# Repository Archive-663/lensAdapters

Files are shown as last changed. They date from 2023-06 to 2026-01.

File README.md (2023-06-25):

# Lot no. 002 | Lens Adapters

A collection of lens adapters for a wide variety of cameras.

I'm working on a fully 3d printed adapter for lenses that require a lens locking pin so that the adapters can reach a wider audience without having to buy specialised parts like prewound springs or 2mm rods.

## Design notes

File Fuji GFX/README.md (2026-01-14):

## FujiFilm GFX Lens Adapters

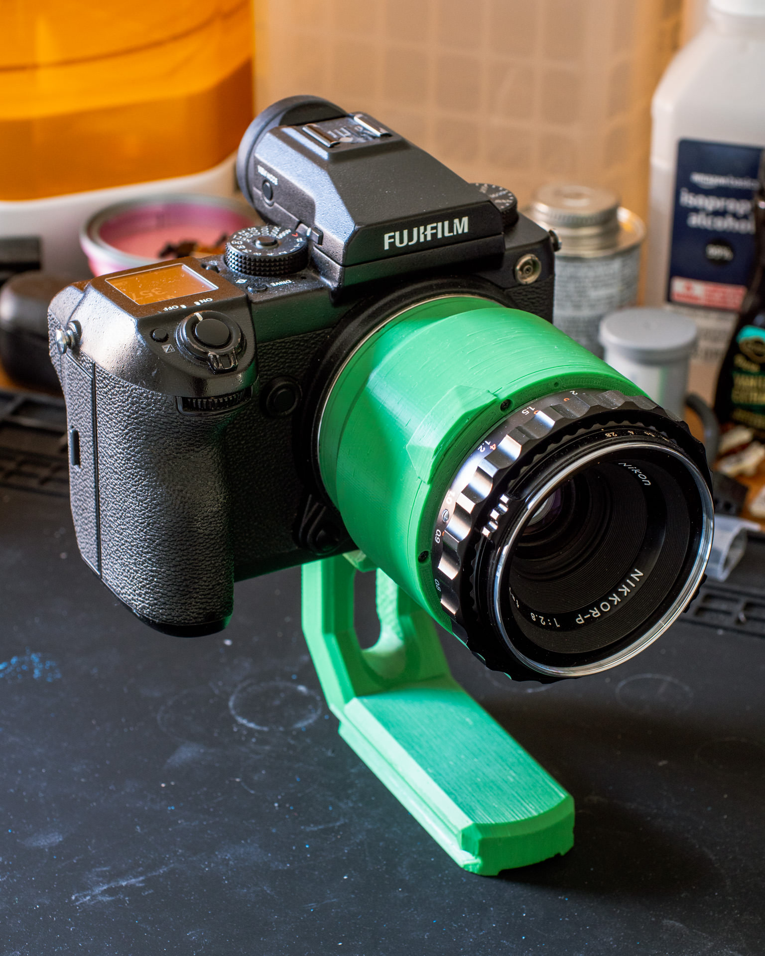
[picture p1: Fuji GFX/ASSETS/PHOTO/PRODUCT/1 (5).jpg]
GFXlensAdapter


### In this repository:
- [GFX Dumb Lens Adapters](https://github.com/Archive-663/lensAdapters/tree/main/Fuji%20GFX/DUMB)

### Story Time:
The GFX has always been my grail camera. While yes, this is old and some what cumbersom, the images coming from the sensor are amazing. The adapters for the GFX are expensive, and unsurprisingly, I'm a cheap ass. So I've spent some time making a few dumb adapters for the GFX. I'm in the process of designing a shift adapter for certain mounts as well, but they will come later.

### Help support Archive 663 with a dontation or monthly sub



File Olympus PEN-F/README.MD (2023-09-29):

# Olympus PEN-F Dumb, Shift, and Speedbooster Adapters

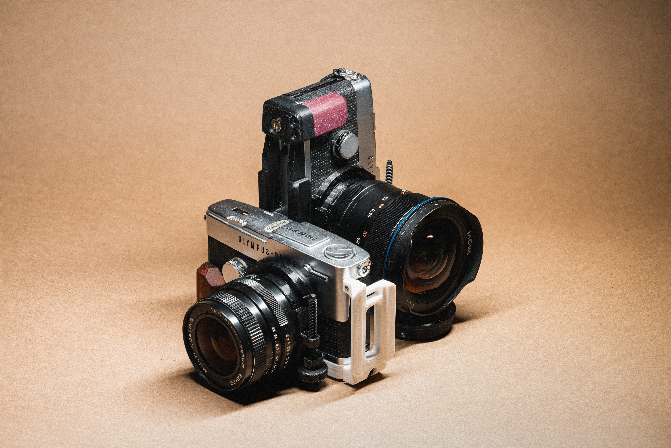
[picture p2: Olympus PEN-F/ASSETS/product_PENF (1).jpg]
productPhoto001


### In this repository:
- [Pen-F Dumb Lens Adapters](https://github.com/Archive-663/lensAdapters/tree/main/Olympus%20PEN-F/DUMB)
- [Pen-F Shift Lens Adapters](https://github.com/Archive-663/lensAdapters/tree/main/Olympus%20PEN-F/SHIFT)
- [Pen-F Speedbooster Lens Adapters](https://github.com/Archive-663/lensAdapters/tree/main/Olympus%20PEN-F/SPEEDBOOSTER)

### Story Time:
I picked up an Olympus PEN-F a while ago to see if there was any chance I could adapt some modern APS-C mirrorless or DLSR lenses to better it's lens selection. The unfortunate answer is that it's mostly "no." While the flange focal distance is pretty short, the mirror actually protrudes too much into the actual lens mount so more often than not the mirror would slap the rear lens element of most adapted mirrorless and even Leica M mount lenses. There is hope for APS-C DSLR lenses. I'm working on adapting a zoom lens and trying to figure out how to make a much more compact circular fish eye lense out of a few Meike lenses.

So while mirrorless lenses were out of the question, there was still a significant gap between me using DSLR lenses on my PEN-F. I could only find a third-party EF to PEN-F adapter and the official PEN-F adapters were few and far between online. So, I figured let's fix that issue while having some fun. I started with the M42 mount because the mount is pretty easy to build on since there are no moving parts that engage from the camera mount to the lens flange. But really, the only way to open up more lenses was to develop an easy to print and assemble Nikon F and Canon EF adapter.

Since, both, Canon and Nikon have a pin lock system, I needed to design a reliable pin locking system that was easy to print with few bought parts. I came up with a simple wedge lever locking system to positively engage the locking pins into the cavity on the lens flanges. It works reliably, prints well, and doesn't require any premade springs or parts. I wanted to do it this way to increase the accessiblilty of the adapters. With fewer parts that need to be bought it's easier for anyone in the world to print, assemble, and use; only having to purchase standardized M1.6 x 6mm machine screws.

Funnily enough, the designing of the shift lenses required me to design an L-Bracket system for the Pen-F cameras. Which can be found here: [Lot no. 007 | Olympus Pen-F accessories](https://github.com/Archive-663/olympusPENF)

### Help support Archive 663 with a dontation or monthly sub



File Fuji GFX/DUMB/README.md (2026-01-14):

## GFX Dumb Lens Adapters

A collection of basic dumb adapters for using non-Fuji GFX lenses on Fuji GFX cameras.

### Features:
- Available for Bronica S2.
- More mounts coming soon.

### To Print:
- Download the files in the mountDumbBase folder for the GFX Mount
- Download the files for the camera mount you want to adapt. They all use the same GFX mount so keeping them separate makes it easier to update when I need to. 

### Help support Archive 663 with a dontation or monthly sub



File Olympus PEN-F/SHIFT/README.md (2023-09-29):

## PEN-F Shift Lens Adapters

olympusPENFShiftAdapters

A collection of basic shift adapters for using SLR/DSLR lenses on Olympus Pen-F cameras.

### Features:
- +/- 7mm of shift.
- 90 degree rotation for both portrait and landscape shift.
- Available for M42, & Nikon F.
- Interchangeable base PEN-F bottom shift assembly. Print once and slide on and off either of the top shift assemblies.
- More mounts coming soon.

### Help support Archive 663 with a dontation or monthly sub



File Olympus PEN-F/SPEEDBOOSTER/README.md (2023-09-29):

## PEN-F Speedbooster Lens Adapters

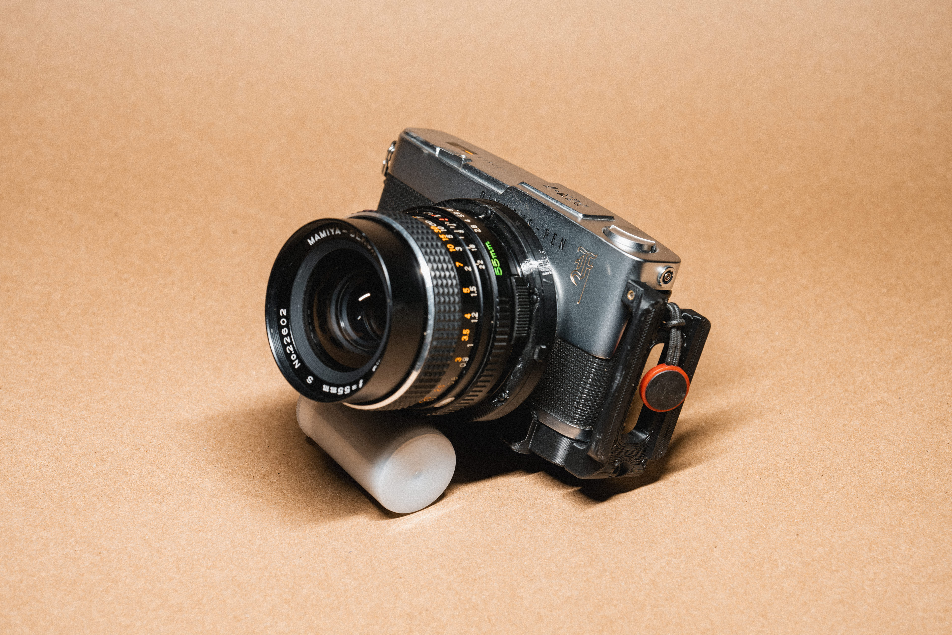
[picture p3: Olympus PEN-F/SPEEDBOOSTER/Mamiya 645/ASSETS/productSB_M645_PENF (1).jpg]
olympusPENFSpeedboosterAdapters


A collection of experimental shift adapters for using Medium Format lenses on Olympus Pen-F cameras.

### Features:
- 0.71x focal reduction
- More mounts coming soon.

### Help support Archive 663 with a dontation or monthly sub



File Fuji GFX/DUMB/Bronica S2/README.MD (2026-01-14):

## Bronica S2 to Fuji GFX Dumb Adapter

productPhoto001

### Features:
- All-in-one Coil Spring Aperture Lever
- Print in place Lens Lock/Release

### What you'll need:
- 12x M1.6 x 5mm pan head or self-tapping screws
- 1x M1.6 tap (If using a machine screw)

### What would be helpful:
- M1.4 drill bit
- M1.8/M2 drill bit

### Printing help:
Filament recommendation:
- ABS
- PETG

Generally, all my designs have chamfers on the print face of the STL. You can reference the supplied 'printOrientation' .3mf files for suggested print orientation.

### Assembly help:
Drill holes to their correct tap size before tapping.
- M1.6 requires M1.4 bore followed by an M1.6 tap.
- M1.8 or M2 bore on flanges.

To assemble correctly, use indexing dots to orient the parts. For the Aperture Lever Spring, the indexing dot should point up if looking straight through the dumb body.

Please view the _assembly.stp file for help in parts orientation. If you do not have a CAD program, <a href="https://www.freecad.org/downloads.php" target="_blank">download FreeCAD</a> to view the assembly file and better understand how it should assemble. If using FreeCAD, the naming conventions should carry over and you will be able to see which lens element you need from the various smartphone lenses. (Verified in FreeCAD 0.18) If using something like Solid Edge open the file as an assembly to retain the names of the parts.

### Help support Archive 663 with a dontation or monthly sub



### Samples:
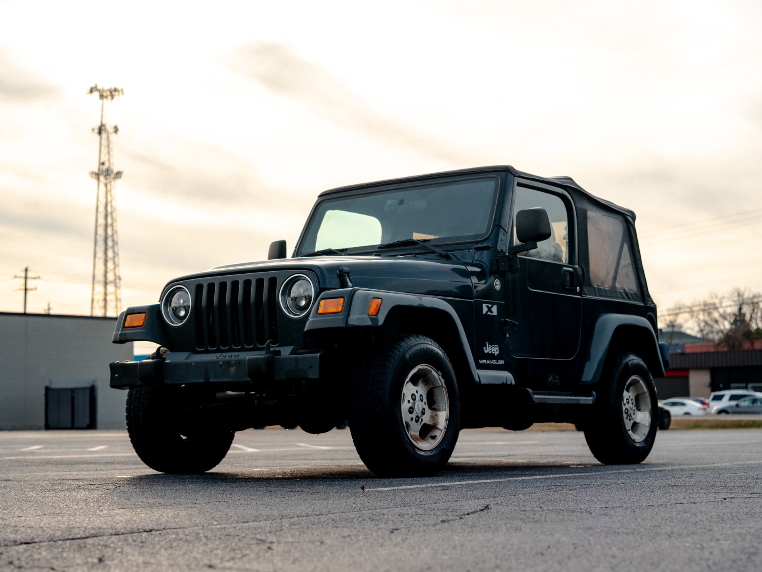
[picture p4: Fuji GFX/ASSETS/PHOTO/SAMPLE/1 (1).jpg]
samplePhoto001

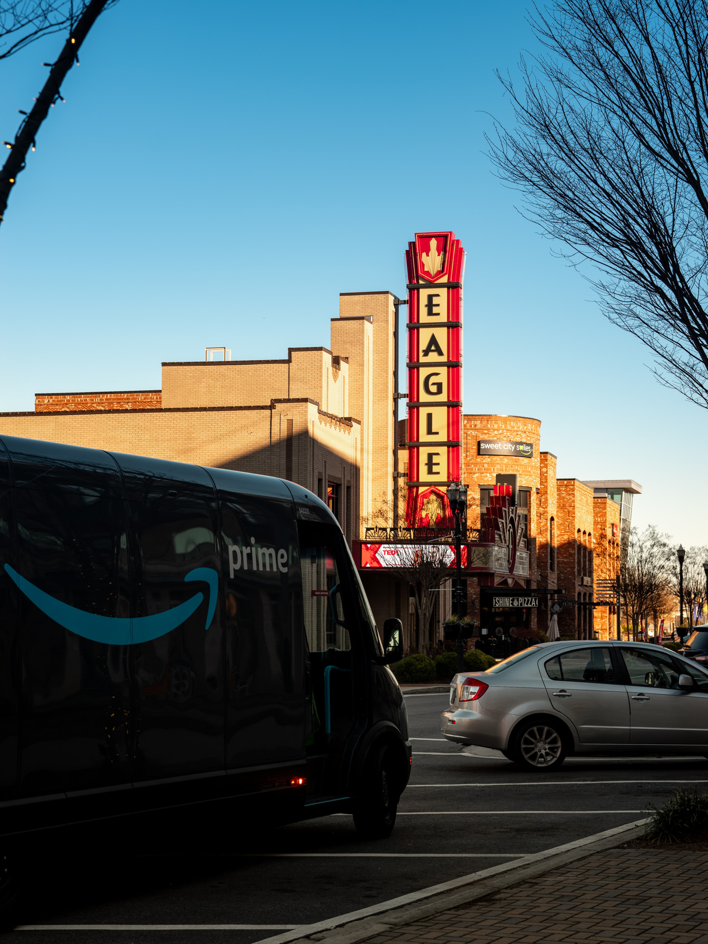
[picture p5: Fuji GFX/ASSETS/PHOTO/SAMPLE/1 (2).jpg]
samplePhoto002

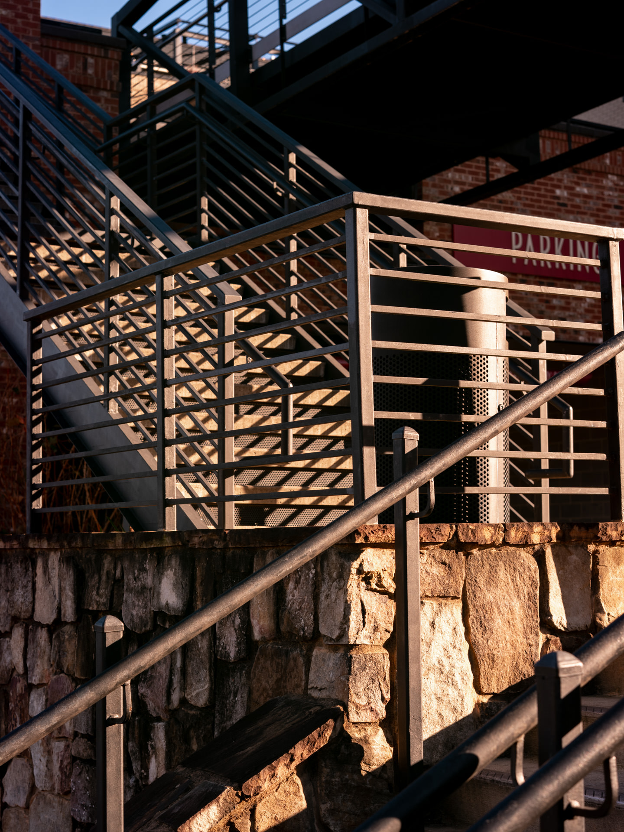
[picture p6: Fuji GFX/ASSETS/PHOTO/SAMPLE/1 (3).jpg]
samplePhoto003

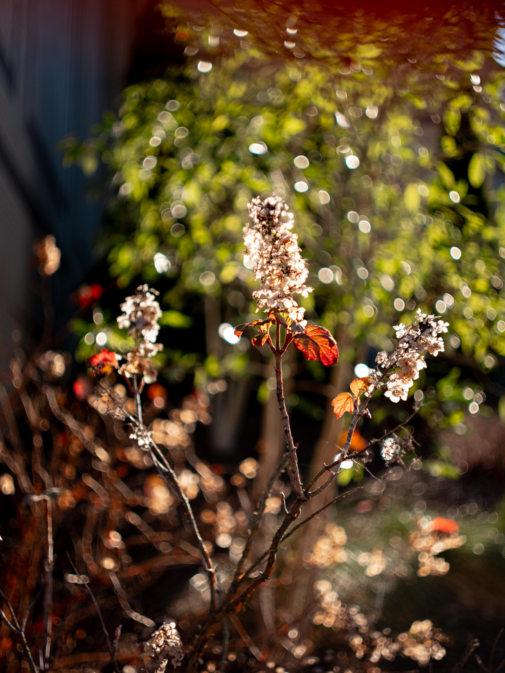
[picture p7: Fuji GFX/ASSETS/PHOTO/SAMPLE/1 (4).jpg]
samplePhoto004


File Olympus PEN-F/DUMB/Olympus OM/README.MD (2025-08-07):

## Olympus OM to PEN-F Dumb Adapter

### Features:
- Adapts OM lenses to PEN-F

### What you'll need:
- 7x M1.6 x 5mm pan head or self-tapping screws
- 1x M1.6 tap (if using standard machine screws and not self-tapping)

### What would be helpful:
- M1.4 drill bit
- M1.8/M2 drill bit

### Printing help:
Filament recommendation:
- ABS
- PETG

Generally, all my designs have chamfers on the print face of the STL. You can reference the supplied 'printOrientation' .3mf files for suggested print orientation.

### Assembly help:
Download the PEN-F mount and locking pin under the mountDumbBase_PENF folder in the DUMB adapters folder on github

Drill holes to their correct tap size before tapping.
- M1.6 requires M1.4 bore followed by an M1.6 tap.
- M1.8 or M2 bore on Rotator part.

To assemble correctly, use indexing dots to orient the parts.

Please view the _assembly.stp file for help in parts orientation. If you do not have a CAD program, <a href="https://www.freecad.org/downloads.php" target="_blank">download FreeCAD</a> to view the assembly file and better understand how it should assemble. If using FreeCAD, the naming conventions should carry over and you will be able to see which lens element you need from the various smartphone lenses. (Verified in FreeCAD 0.18) If using something like Solid Edge open the file as an assembly to retain the names of the parts.

### Help support Archive 663 with a dontation or monthly sub



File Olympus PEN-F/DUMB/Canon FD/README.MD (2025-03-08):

## Canon FD to PEN-F Dumb Adapter

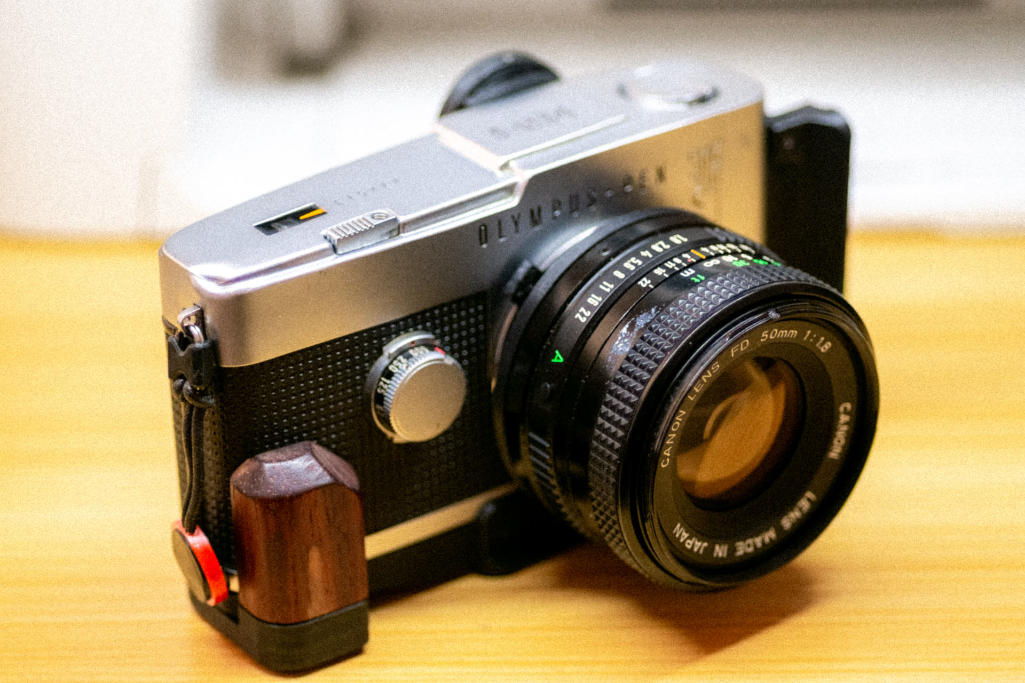
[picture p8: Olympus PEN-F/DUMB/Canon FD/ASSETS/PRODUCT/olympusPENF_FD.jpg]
productPhoto001


### Features:
- Simple aperture pin lock.

productPhoto002

### What you'll need:
- 3x M1.6 x 5mm pan head or self-tapping screws
- 1x M1.6 tap

### What would be helpful:
- M1.4 drill bit
- M1.8/M2 drill bit

### Printing help:
Filament recommendation:
- ABS
- PETG

Generally, all my designs have chamfers on the print face of the STL. You can reference the supplied 'printOrientation' .3mf files for suggested print orientation.

### Assembly help:
Drill holes to their correct tap size before tapping.
- M1.6 requires M1.4 bore followed by an M1.6 tap.
- M1.8 or M2 bore on Rotator part.

To assemble correctly, use indexing dots to orient the parts.

Please view the _assembly.stp file for help in parts orientation. If you do not have a CAD program, <a href="https://www.freecad.org/downloads.php" target="_blank">download FreeCAD</a> to view the assembly file and better understand how it should assemble. If using FreeCAD, the naming conventions should carry over and you will be able to see which lens element you need from the various smartphone lenses. (Verified in FreeCAD 0.18) If using something like Solid Edge open the file as an assembly to retain the names of the parts.

### Help support Archive 663 with a dontation or monthly sub



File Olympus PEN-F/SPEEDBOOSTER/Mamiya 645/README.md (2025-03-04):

## M645 to PEN-F Speedbooster Adapter

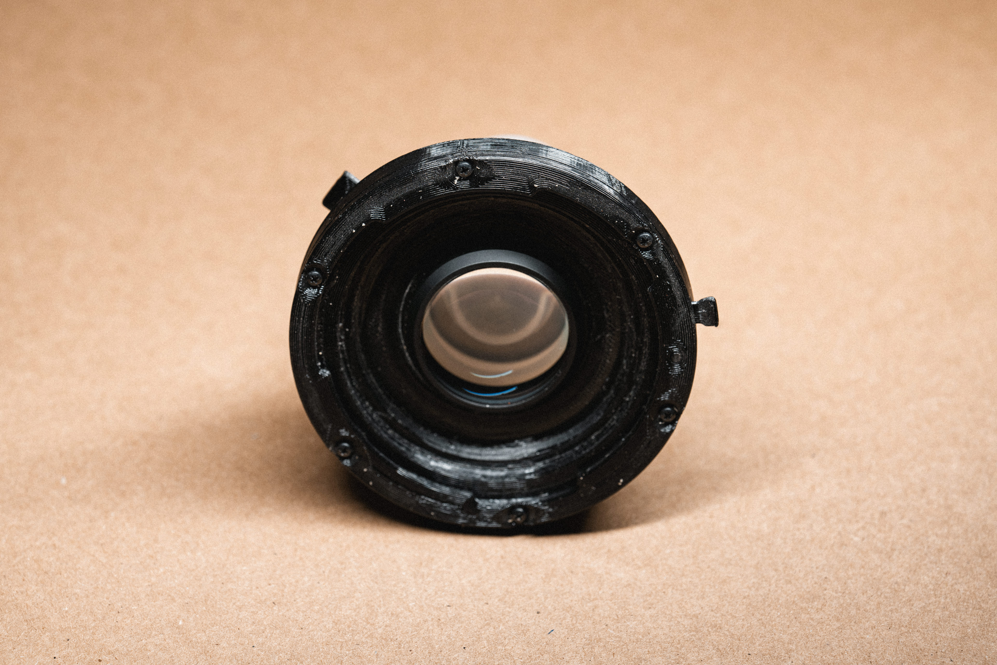
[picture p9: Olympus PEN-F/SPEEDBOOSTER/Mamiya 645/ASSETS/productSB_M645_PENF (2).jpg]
olympusPENFSpeedboosterAdapterforM645Lenses


### Features:
- 0.71x focal reduction

### What you'll need:
- Viltrox or similar speedbooster/focal reducer element
- 9x M1.6 x 5mm pan head screws
- 1x M1.6 tap

### What would be helpful:
- M1.4 drill bit
- M1.8/M2 drill bit

### Printing help:
Filament recommendation:
- ABS
- PETG

Generally, all my designs have chamfers on the print face of the STL. You can reference the supplied 'printOrientation' .3mf files for suggested print orientation.

### Assembly help:
The speedbooster element needs to be press fit into the housing. You may need to wrap a bit of gaffer's tape around the threads of the element to have it press fit snuggly. 

Install the speedbooster element flipped from it's standard orientation in the original speedbooster. 

Drill holes to their correct tap size before tapping.
- M1.6 requires M1.4 bore followed by an M1.6 tap.
- M1.8 or M2 bore on Mount Rings part.

When assembling the rotating, and shift assemblies use synthetic grease similar to Super Lube PTFE or keycap lube to make the shift and rotate function smoother. It will help with parts longevity as well. Additionally, grease the threads on the machine screw to allow for smoother engagement.

Please view the _assembly.stp file for help in parts orientation. If you do not have a CAD program, <a href="https://www.freecad.org/downloads.php" target="_blank">download FreeCAD</a> to view the assembly file and better understand how it should assemble. If using FreeCAD, the naming conventions should carry over and you will be able to see which lens element you need from the various smartphone lenses. (Verified in FreeCAD 0.18) If using something like Solid Edge open the file as an assembly to retain the names of the parts.

### Help support Archive 663 with a dontation or monthly sub



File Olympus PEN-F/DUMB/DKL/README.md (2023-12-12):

## Deckel DKL to PEN-F Dumb Adapter

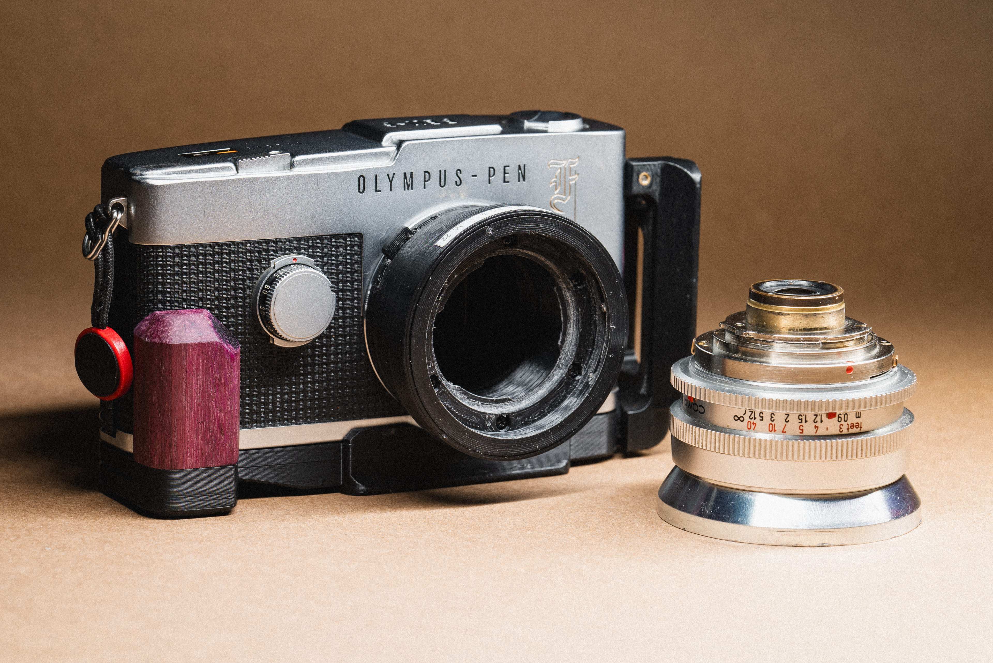
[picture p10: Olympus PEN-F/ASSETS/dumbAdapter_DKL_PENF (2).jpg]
DKL to PENF adapter


### Features:
- Simple Push/Pull Lens Lock System.
- Basic F-stop printable label from F/2 to F/22

### What you'll need:
- 9x M1.6 x 5mm pan head screws (if using PETG)

OR

- 9x M1.6/1.7 x 5mm self tapping screws (if using ABS or PETG)
- 1x M1.6 tap
- 1x M2 x 7mm set screw or pan head screw

### What would be helpful:
- M1.4 drill bit
- M1.8/M2 drill bit

### Printing help:
Filament recommendation:
- ABS
- PETG

Generally, all my designs have chamfers on the print face of the STL. You can reference the supplied 'printOrientation' .3mf files for suggested print orientation.

### Assembly help:
Drill holes to their correct tap size before tapping.
- M1.6 requires M1.4 bore followed by an M1.6 tap.
- M1.8 or M2 bore on Rotator part.

The aperture is controlled by the M2 x 7mm set screw. If you're using ABS I didn't like how the threads felt using a tap, so I'd suggest just screwing the M2 set screw in without a tap. ABS doesn't hold threads as well as PETG which is why I advise using self tapping screws with ABS. It's just, in the case of, the aperture control is better with a flat bottom screw vs the pointed bottom of the self tapping screws.

To assemble correctly, use indexing dots to orient the parts.

Please print the supplied 'dumbAdapter_DKL_-_PENF_apertureLabel.pdf' found in the ASSETS folder on adhesive backed paper or apply an adhesive to the back. Then apply it to the aperture ring when you are wide open. Matching the aperture mark with the f-stop number your lens is wide open. F/1.9 is as good as F/2. 

Please view the _assembly.stp file for help in parts orientation. If you do not have a CAD program, <a href="https://www.freecad.org/downloads.php" target="_blank">download FreeCAD</a> to view the assembly file and better understand how it should assemble. If using FreeCAD, the naming conventions should carry over and you will be able to see which lens element you need from the various smartphone lenses. (Verified in FreeCAD 0.18) If using something like Solid Edge open the file as an assembly to retain the names of the parts.

### Help support Archive 663 with a dontation or monthly sub



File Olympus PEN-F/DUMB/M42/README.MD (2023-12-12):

## M42 to PEN-F Dumb Adapter

### Features:
- Adjustable M42 thread mount to allow for fine tuning lens alignment

### What you'll need:
- 4x M3 x 3mm grub screws (set screws)
- 3x M1.6 x 5mm pan head screws
- 1x M3 tap
- 1x M1.6 tap

### What would be helpful:
- M1.4 drill bit
- M1.8/M2 drill bit
- M2.5 drill bit

### Printing help:
Filament recommendation:
- ABS
- PETG

Generally, all my designs have chamfers on the print face of the STL. You can reference the supplied 'printOrientation' .3mf files for suggested print orientation.

### Assembly help:
Drill holes to their correct tap size before tapping.
- M1.6 requires M1.4 bore followed by an M1.6 tap.
- M1.8 or M2 bore on Rotator part.
- M3 requires M2.5 bore followed by an M3 tap.

To assemble correctly, use indexing dots to orient the parts.

Please view the _assembly.stp file for help in parts orientation. If you do not have a CAD program, <a href="https://www.freecad.org/downloads.php" target="_blank">download FreeCAD</a> to view the assembly file and better understand how it should assemble. If using FreeCAD, the naming conventions should carry over and you will be able to see which lens element you need from the various smartphone lenses. (Verified in FreeCAD 0.18) If using something like Solid Edge open the file as an assembly to retain the names of the parts.

### Help support Archive 663 with a dontation or monthly sub



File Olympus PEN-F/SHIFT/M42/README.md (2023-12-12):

## M42 to PEN-F Shift Adapter

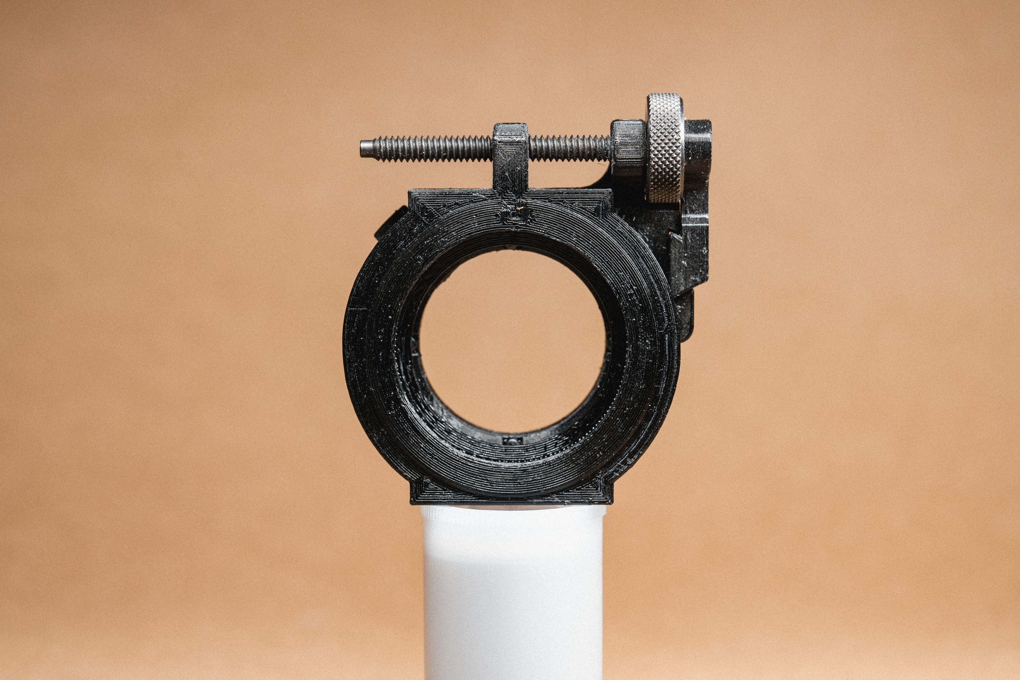
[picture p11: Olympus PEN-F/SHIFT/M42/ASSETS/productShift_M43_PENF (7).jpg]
olympusPENFShiftAdapterforM42Lenses


### Features:
- +/- 7mm of shift
- 90 degree rotation for both portrait and vertical shift

### What you'll need:
- Either
  - 1x M5 x 50mm hex head machine screw
  - 1x 10-24 x 2" hex head machine screw
  - or 1x 10-32 x 2" hex head machine screw
- 4x M3 x 3mm set screws (or grub screws)
- 5x M1.6 x 5mm pan head screws
- 1x M3 tap
- 1x M1.6 tap
- 1x M5/10-24/10-32 tap

### What would be helpful:
- M1.4 drill bit
- M1.8/M2 drill bit
- M2.5 drill bit
- M4.2 drill bit
- M4.5/No. 25 drill bit
- M5 or 3/16 drill bit

### Printing help:
Filament recommendation:
- ABS
- PETG

Generally, all my designs have chamfers on the print face of the STL. You can reference the supplied 'printOrientation' .3mf files for suggested print orientation.

### Assembly help:
Drill holes to their correct tap size before tapping.
- M5 requires M4.2 bore followed by an M5 tap
- 10-24/10-32 requires M4.5/No. 25 bore followed by a 10-24/10-32 tap
- M3 requires M2.5 bore followed by an M3 tap.
- M1.6 requires M1.4 bore followed by an M1.6 tap.
- M1.8 or M2 bore on Rotator part.

When assembling the rotating, and shift assemblies use synthetic grease similar to Super Lube PTFE or keycap lube to make the shift and rotate function smoother. It will help with parts longevity as well. Additionally, grease the threads on the machine screw to allow for smoother engagement.

Please view the _assembly.stp file for help in parts orientation. If you do not have a CAD program, <a href="https://www.freecad.org/downloads.php" target="_blank">download FreeCAD</a> to view the assembly file and better understand how it should assemble. If using FreeCAD, the naming conventions should carry over and you will be able to see which lens element you need from the various smartphone lenses. (Verified in FreeCAD 0.18) If using something like Solid Edge open the file as an assembly to retain the names of the parts.

### Help support Archive 663 with a dontation or monthly sub



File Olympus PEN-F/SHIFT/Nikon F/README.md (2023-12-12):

## Nikon F to PEN-F Shift Adapter

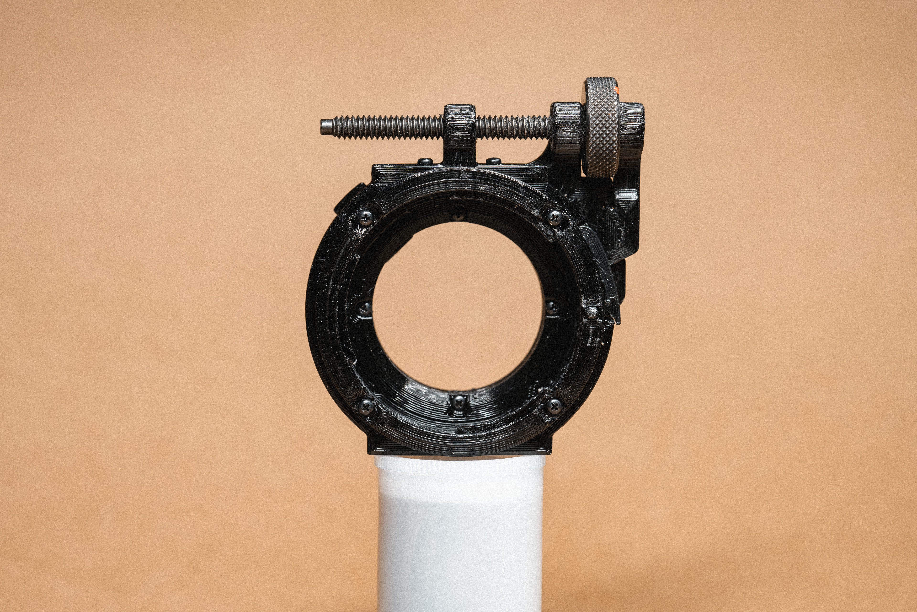
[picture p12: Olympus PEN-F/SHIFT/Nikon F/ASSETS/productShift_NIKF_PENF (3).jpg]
olympusPENFShiftAdapterforNIKONFLenses


### Features:
- +/- 7mm of shift
- 90 degree rotation for both portrait and vertical shift

### What you'll need:
- Either
  - 1x M5 x 50mm hex head machine screw
  - 1x 10-24 x 2" hex head machine screw
  - or 1x 10-32 x 2" hex head machine screw
- 14x M1.6 x 5mm pan head screws
- 1x M1.6 tap
- 1x M5/10-24/10-32 tap

### What would be helpful:
- M1.4 drill bit
- M1.8/M2 drill bit
- M4.2 drill bit
- M4.5/No. 25 drill bit
- M5 or 3/16 drill bit

### Printing help:
Filament recommendation:
- ABS
- PETG

Generally, all my designs have chamfers on the print face of the STL. You can reference the supplied 'printOrientation' .3mf files for suggested print orientation.

### Assembly help:
Drill holes to their correct tap size before tapping.
- M5 requires M4.2 bore followed by an M5 tap
- 10-24/10-32 requires M4.5/No. 25 bore followed by a 10-24/10-32 tap
- M1.6 requires M1.4 bore followed by an M1.6 tap.
- M1.8 or M2 bore on Rotator part.

When assembling the rotating, and shift assemblies use synthetic grease similar to Super Lube PTFE or keycap lube to make the shift and rotate function smoother. It will help with parts longevity as well. Additionally, grease the threads on the machine screw to allow for smoother engagement.

Please view the _assembly.stp file for help in parts orientation. If you do not have a CAD program, <a href="https://www.freecad.org/downloads.php" target="_blank">download FreeCAD</a> to view the assembly file and better understand how it should assemble. If using FreeCAD, the naming conventions should carry over and you will be able to see which lens element you need from the various smartphone lenses. (Verified in FreeCAD 0.18) If using something like Solid Edge open the file as an assembly to retain the names of the parts.

### Help support Archive 663 with a dontation or monthly sub



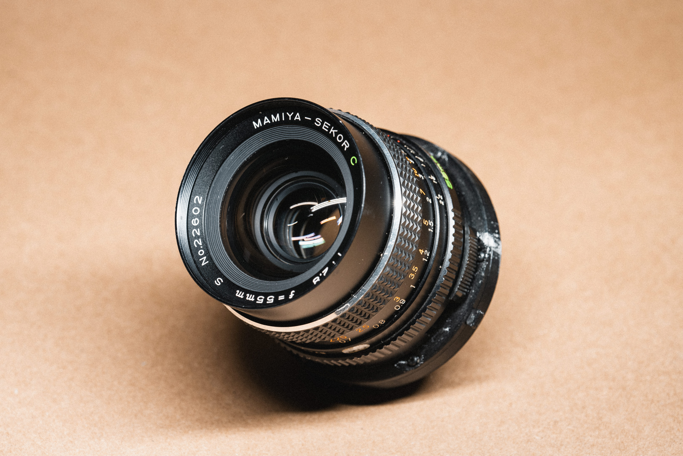
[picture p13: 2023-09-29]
Olympus PEN-F/SPEEDBOOSTER/Mamiya 645/ASSETS/productSB_M645_PENF (5).jpg

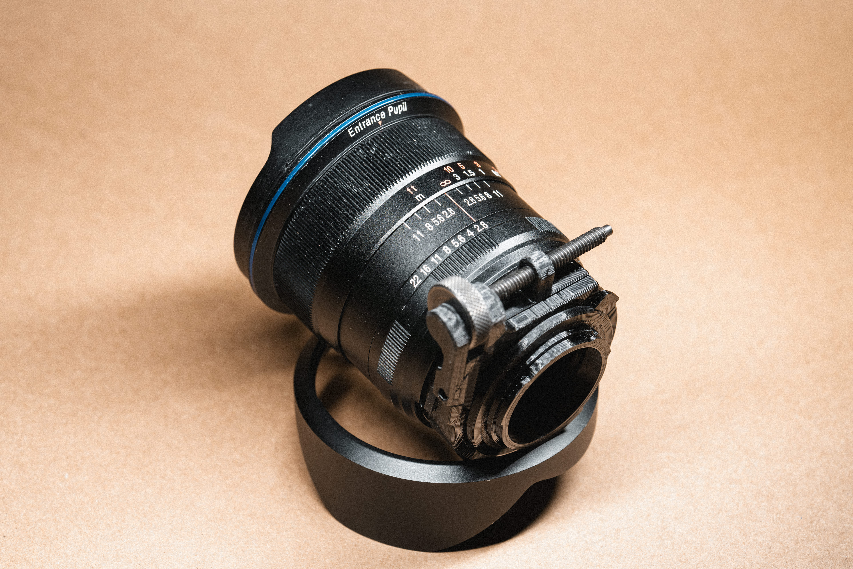
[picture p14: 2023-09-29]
Olympus PEN-F/SHIFT/Nikon F/ASSETS/productShift_NIKF_PENF (6).jpg

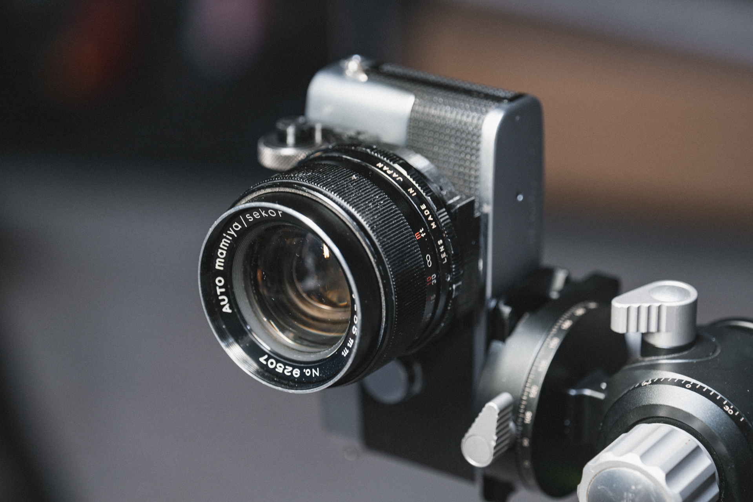
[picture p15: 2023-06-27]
Olympus PEN-F/SHIFT/M42/ASSETS/productShift_M43_PENF (3).jpg

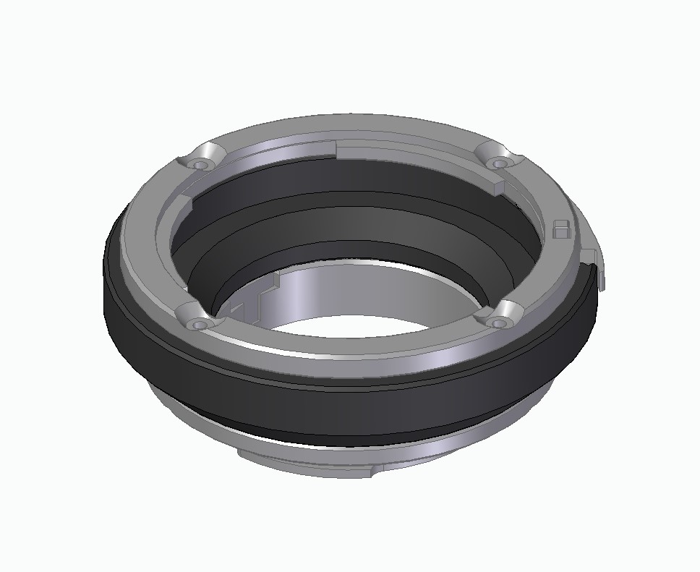
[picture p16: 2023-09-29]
Olympus PEN-F/ASSETS/dumbAdapter_PENF_crop.jpg

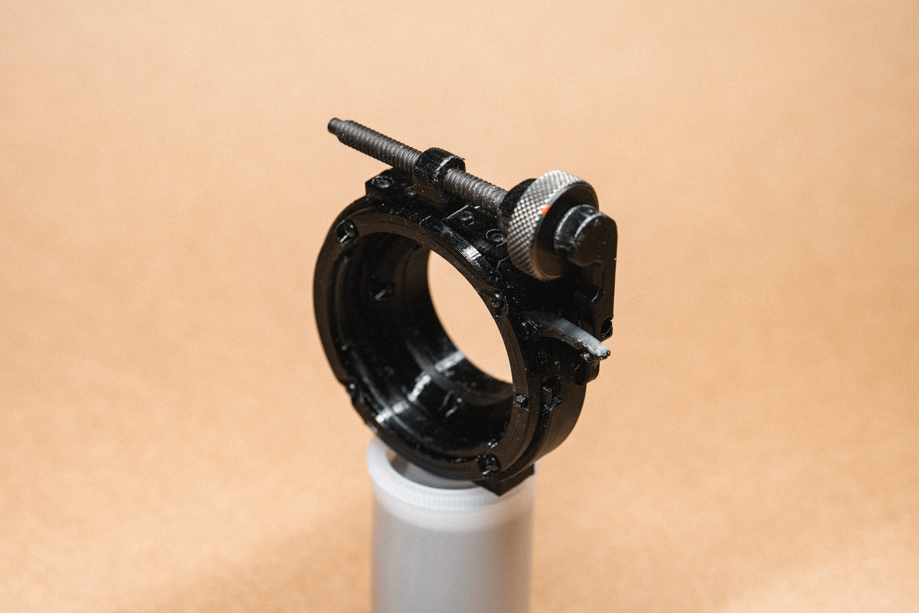
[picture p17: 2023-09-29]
Olympus PEN-F/SHIFT/Nikon F/ASSETS/productShift_NIKF_PENF (2).jpg

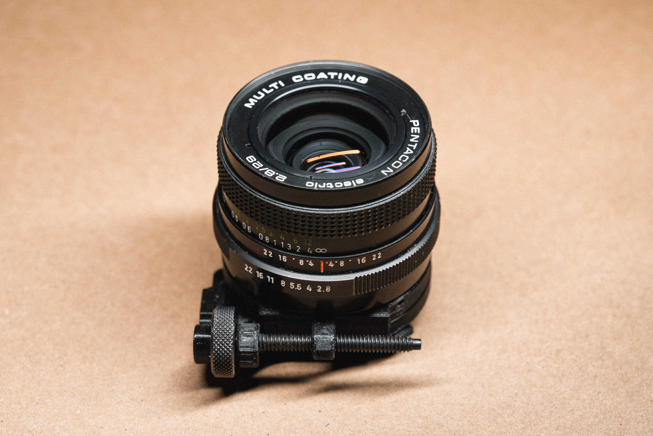
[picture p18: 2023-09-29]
Olympus PEN-F/SHIFT/M42/ASSETS/productShift_M43_PENF (10).jpg

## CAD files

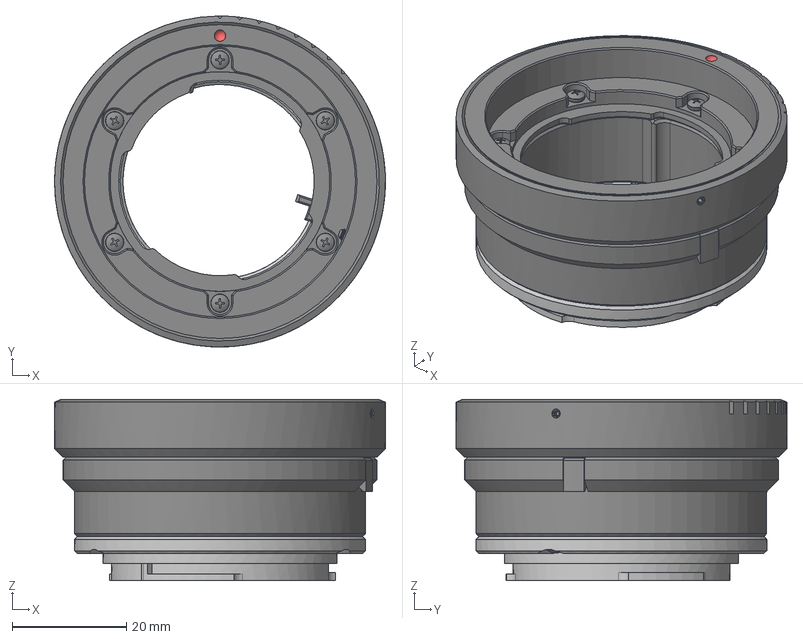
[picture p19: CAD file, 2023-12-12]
Olympus PEN-F/DUMB/DKL/STEP/dumbBody_DKL_PENF_assembly.stp
58.0 x 58.0 x 31.8 mm
mountLensBase_lensLock_PENF
M2_setScrew_6mm
M1.6_panHead_5mm x 9
mountLensDumbBody_PENF
mountBodyBase_apertureRing_DKL_stepless
mountBodyBase_DKL_stepless
mountBodyBase_lensLock_DKL
dumbBody_DKL_PENF

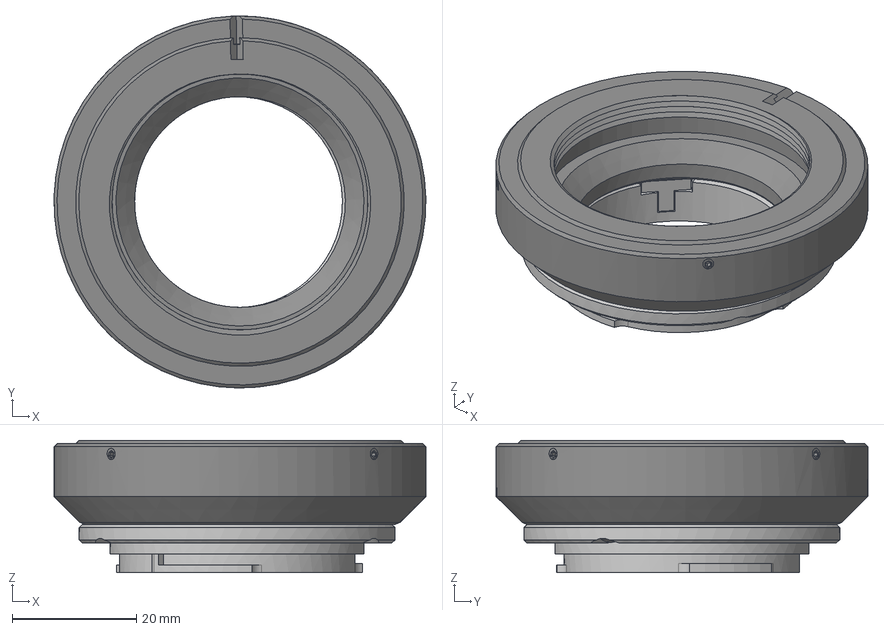
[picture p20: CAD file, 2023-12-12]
Olympus PEN-F/DUMB/M42/STEP/dumbBody_M42_PENF_assembly.stp
60.0 x 60.0 x 21.3 mm
mountLensBase_lensLock_PENF
M2_setScrew_5mm x 4
M1.6_panHead_5mm x 3
mountLensDumbBody_PENF
dumbBody_M42_PENF
mountBodyBase_Thread_M42

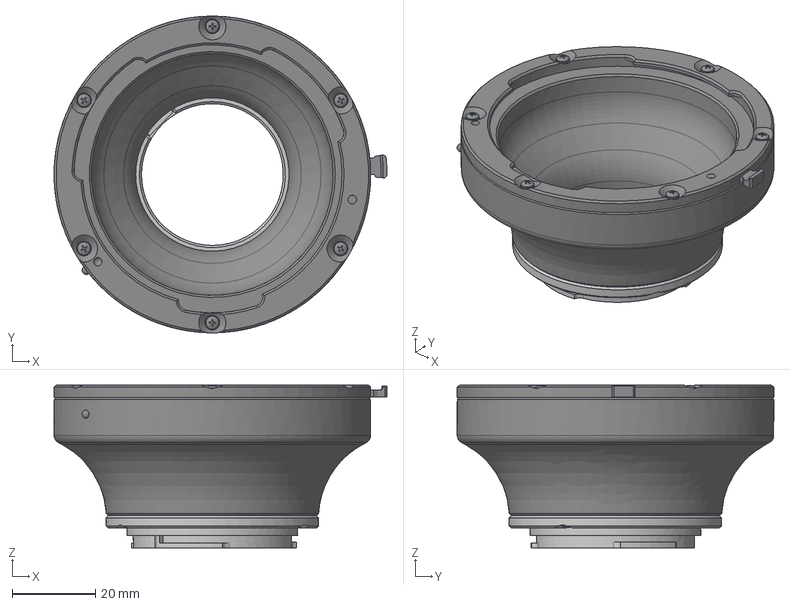
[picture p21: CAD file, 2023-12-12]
Olympus PEN-F/DUMB/Mamiya 645/STEP/dumbBody_M645_PENF_assembly.stp
79.9 x 76.0 x 39.1 mm
mountLensBase_lensLock_PENF
M1.6_panHead_5mm x 9
mountLensDumbBody_PENF
mountBodyBase_lock_M645
mountBodyBase_flange_M645
dumbBody_M645_PENF

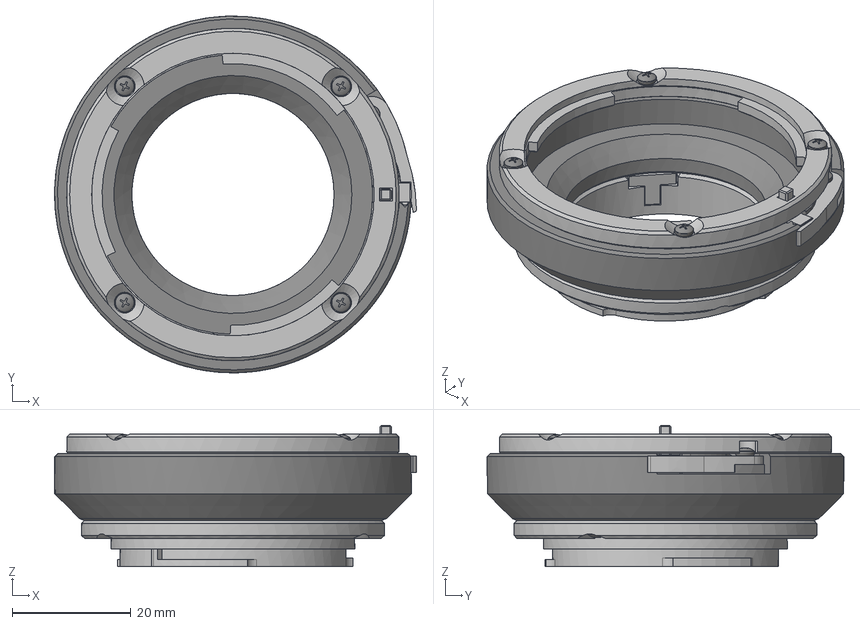
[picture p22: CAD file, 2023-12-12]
Olympus PEN-F/DUMB/Nikon F/STEP/dumbBody_NIKF_PENF_assembly.stp
60.9 x 60.0 x 23.8 mm
mountLensBase_lensLock_PENF
M1.6_panHead_5mm x 8
mountLensDumbBody_PENF
dumbBody_NIKF_PENF
mountBodyBase_pinLock_nikonF
mountBodyBase_flange_nikonF
mountBodyBase_pin_nikonF

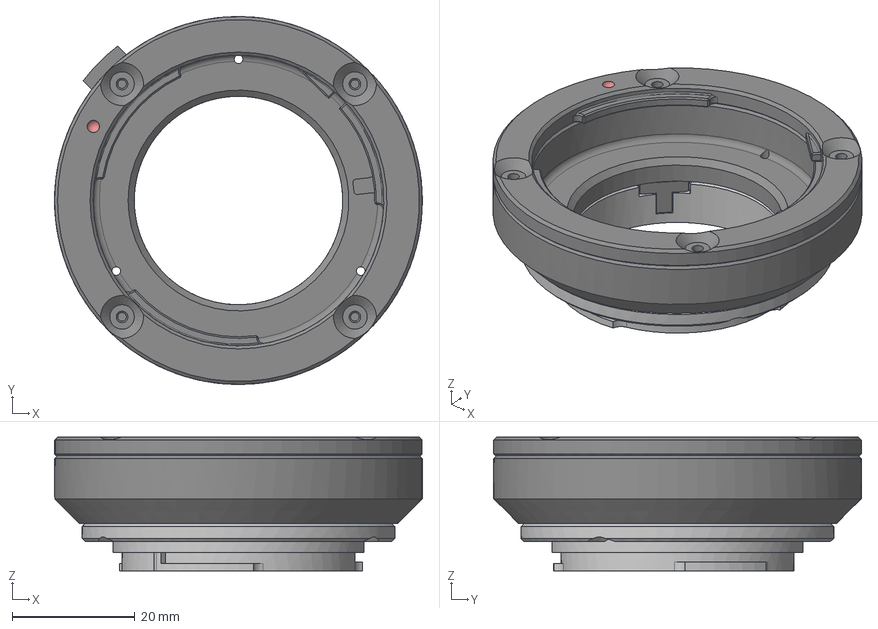
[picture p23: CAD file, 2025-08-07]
Olympus PEN-F/DUMB/Olympus OM/STEP/dumbBody_OM_PENF_assembly.stp
60.0 x 60.0 x 21.8 mm
mountLensBase_lensLock_extended_PENF
mountLensDumbBody_PENF
dumbBodyFlange_OM_PENF
dumbBody_OM_PENF

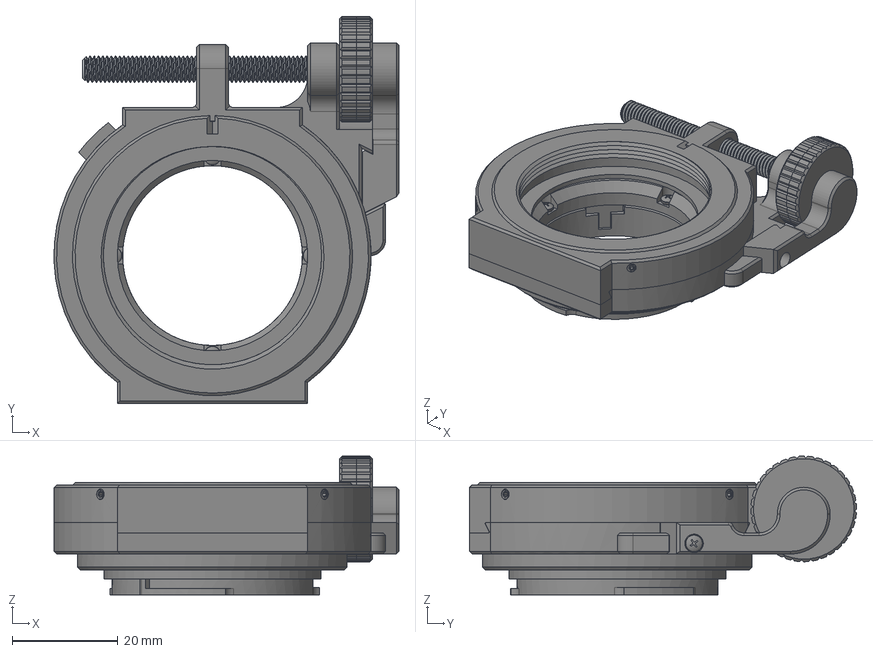
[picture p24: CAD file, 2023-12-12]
Olympus PEN-F/SHIFT/M42/STEP/shiftAdapter_M42_PENF_assemblyMetric.stp
65.3 x 73.3 x 26.3 mm
shiftBaseMount_PENF
shiftBaseRotator_PENF
shiftBaseBottomPlate_PENF
shiftBaseBottomPlate_screwCap_PENF
shiftBaseScrewCap_Top_PENF
shiftBaseMountLock_Extended_PENF
shiftTopPlate_M42_PENF
mountBodyBase_Thread_M42
M2_setScrew_5mm x 4
M5_hexHead_50mm
shiftBaseScrewCap_bottomMetric_PENF
M1.6_panHead_5mm x 5

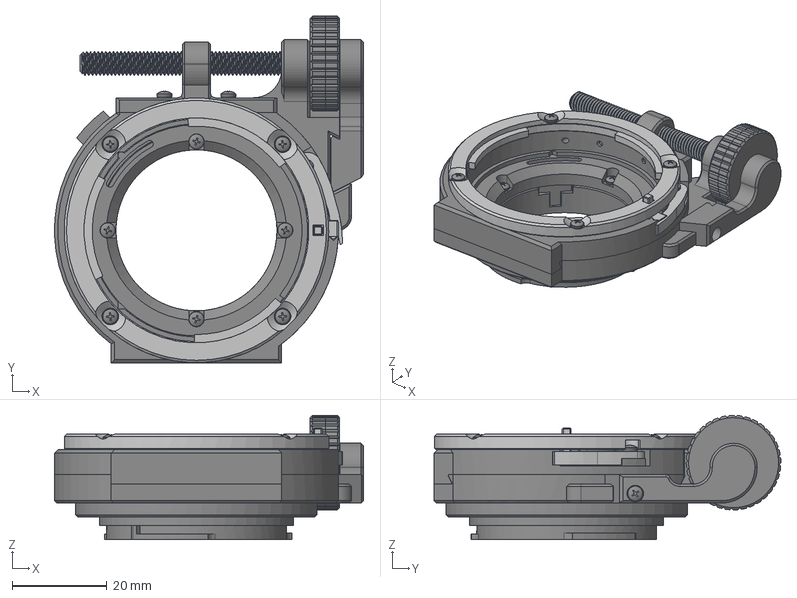
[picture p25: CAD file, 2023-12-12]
Olympus PEN-F/SHIFT/Nikon F/STEP/shiftAdapter_NIKF_PENF_assemblyMetric.stp
65.3 x 73.3 x 26.3 mm
shiftBaseMount_PENF
shiftBaseRotator_PENF
shiftBaseBottomPlate_PENF
shiftBaseBottomPlate_screwCap_PENF
shiftTopPlate_NIKF_PENF
shiftTopPlateShift_NIKF_PENF
mountBodyBase_pinLock_nikonF
mountBodyBase_pin_nikonF
mountBodyBase_flange_nikonF
shiftBaseScrewCap_Top_PENF
shiftBaseMountLock_Extended_PENF
M1.6_panHead_5mm x 14
M5_hexHead_50mm
shiftBaseScrewCap_bottomMetric_PENF

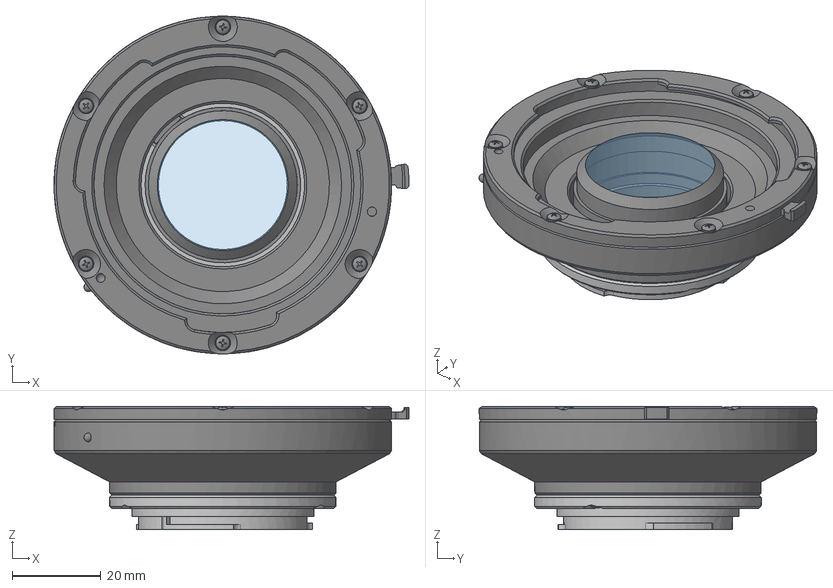
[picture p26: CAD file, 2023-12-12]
Olympus PEN-F/SPEEDBOOSTER/Mamiya 645/STEP/speedBoosterBody_M645_PENF_assembly.stp
79.9 x 76.0 x 27.8 mm
mountLensDumbBody_PENF
mountLensBase_lensLock_extended_PENF
M1.6_panHead_5mm x 9
mountBodyBase_lock_M645
speedBoosterBody_viltroxOptics
mountBodyBase_flange_M645
speedBoosterBody_M645_PENF

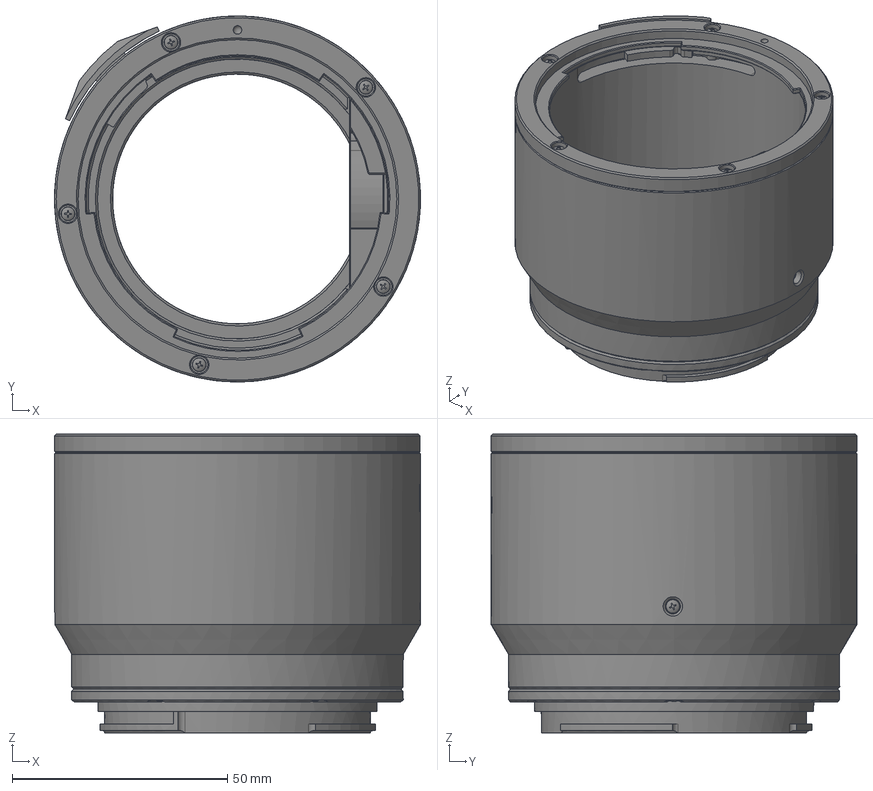
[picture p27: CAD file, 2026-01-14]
Fuji GFX/DUMB/Bronica S2/STEP/dumbAdapter_BS2_GFX_assembly.stp
85.0 x 85.0 x 69.4 mm
M1.6_panHead_5mm x 12
dumbBody_BS_GFX
mountBodyBase_flange_bronicaS2
mountLensBase_flange_GFX
mountBodyBase_apertureSpring_bronicaS2

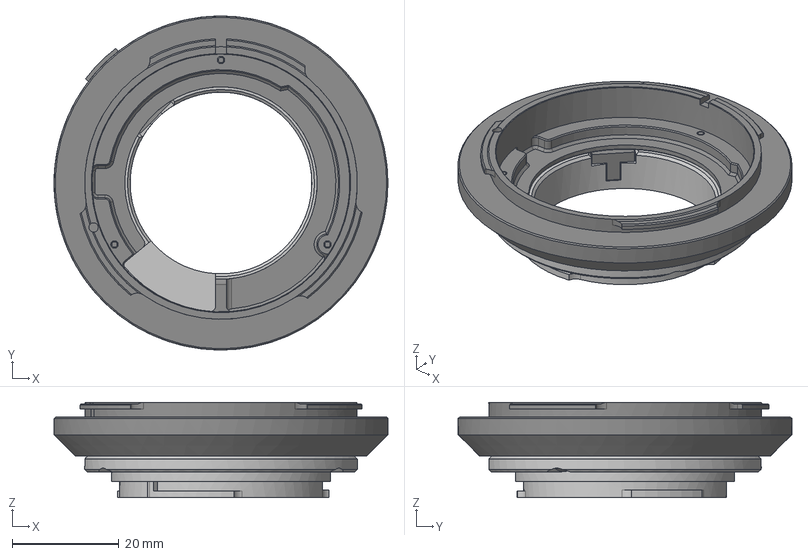
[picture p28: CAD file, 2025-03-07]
Olympus PEN-F/DUMB/Canon FD/STEP/dumbBody_CFD_PENF_assembly.stp
62.5 x 62.5 x 17.8 mm
M1.6_panHead_5mm x 3
mountLensBase_lensLock_extended_PENF
dumbBody_CFD_PENF
mountLensDumbBody_CFD_PENF

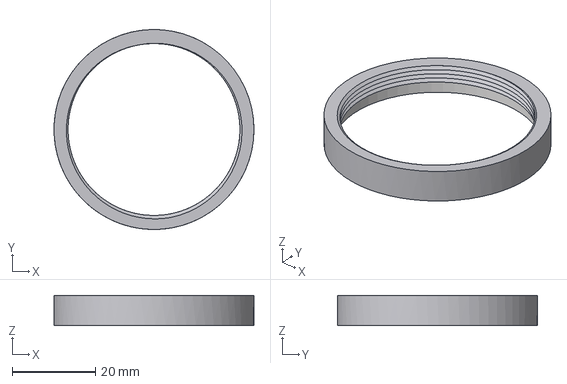
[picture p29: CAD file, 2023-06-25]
Canon EF-Mount/STEP/M42-EF EF Mount Threads.step
48.0 x 48.0 x 7.21 mm

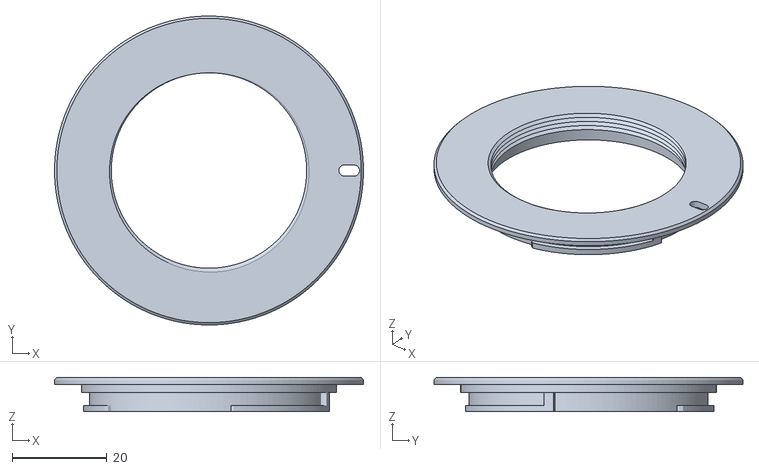
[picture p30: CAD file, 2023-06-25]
Canon EF-Mount/STL/M42_to_canonEF.stl
65.3 x 65.3 x 7.21

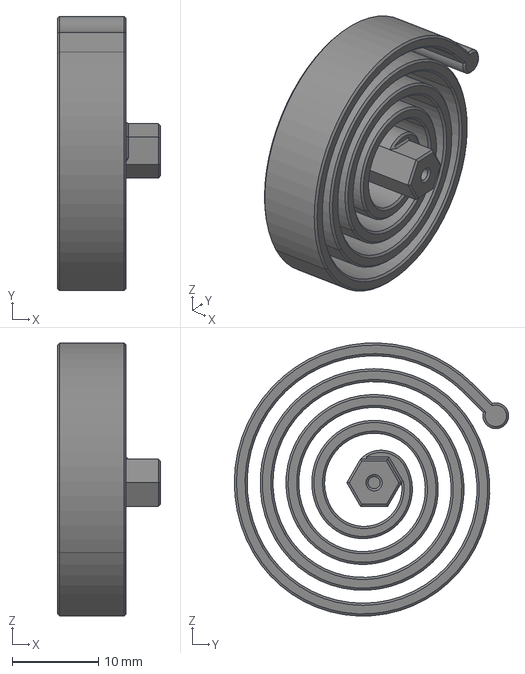
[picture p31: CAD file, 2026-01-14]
Fuji GFX/DUMB/Bronica S2/STEP/mountBodyBase_apertureSpring_BS_GFX.stp
12.0 x 31.9 x 31.7 mm

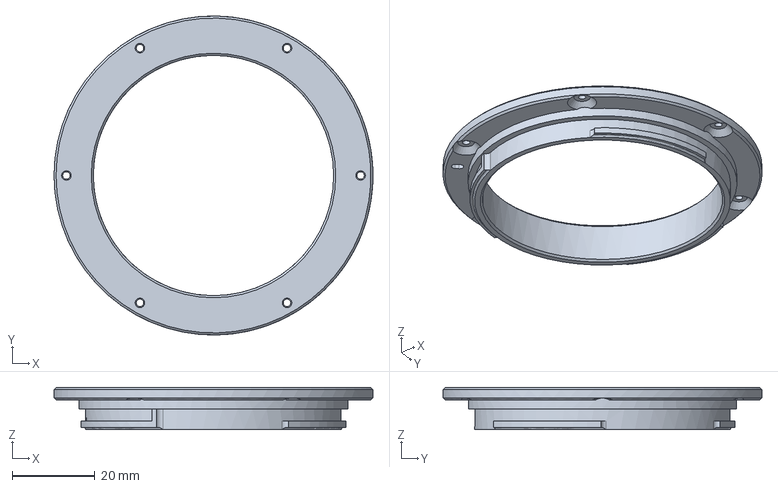
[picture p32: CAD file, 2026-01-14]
Fuji GFX/DUMB/mountDumbBase_GFX/STEP/mountLensBase_flange_GFX.stp
77.0 x 77.0 x 10.2 mm

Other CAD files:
Fuji GFX/DUMB/Bronica S2/STL/mountBodyBase_apertureSpring_bronicaS2.stl
Olympus PEN-F/DUMB/Canon FD/STEP/dumbBody_CFD_PENF.stp
Olympus PEN-F/DUMB/Canon FD/STL/dumbBody_CFD_PENF_printOrientation.3mf
Olympus PEN-F/DUMB/DKL/STL/mountBodyApertureRing_DKL_stepless.stl
Canon EF-Mount/STEP/M42-EF EF Mount Body.step
Fuji GFX/DUMB/Bronica S2/STEP/dumbBody_BS_GFX.stp
Fuji GFX/DUMB/Bronica S2/STEP/mountBodyBase_flange_BS_GFX.stp
Fuji GFX/DUMB/Bronica S2/STL/dumbBody_BS_GFX.stl
Fuji GFX/DUMB/Bronica S2/STL/dumbBody_BS_GFX_printOrientation.3mf
Fuji GFX/DUMB/Bronica S2/STL/mountBodyBase_flange_bronicaS2.stl
Fuji GFX/DUMB/mountDumbBase_GFX/STL/mountLensBase_flange_GFX.stl
Olympus PEN-F/DUMB/Canon FD/STEP/mountLensDumbBody_CFD_PENF.stp
Olympus PEN-F/DUMB/Canon FD/STL/dumbBody_CFD_PENF.stl
Olympus PEN-F/DUMB/Canon FD/STL/mountLensDumbBody_CFD_PENF.stl
Olympus PEN-F/DUMB/DKL/STEP/dumbBody_DKL_PENF.stp
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

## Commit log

2023-06-25 Add M42 to EF STL and Step
    [M42-EF EF Mount Body.step, M42-EF EF Mount Threads.step, M42_to_canonEF.stl]
2023-06-27 Upload M42-PENF Shift Adapter
    [Olympus PEN-F Mount_M42 Body Cap.step, Olympus PEN-F Mount_M42 Body Cap.stl, Olympus PEN-F Mount_Olympus PEN-F Body Cp.step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]
2023-06-27 Upload M42-PENF dumb adapter
    [Olympus PEN-F Mount_M42 Body Cap.step, Olympus PEN-F Mount_M42 Body Cap.stl, Olympus PEN-F Mount_M42-PENF Body.step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]
2023-06-27 Change File Structure
    [Olympus PEN-F Mount_M42 Body Cap.step, Olympus PEN-F Mount_M42 Body Cap.stl, Olympus PEN-F Mount_M42-PENF Body.step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]
2023-09-29 Updated File Structure
    Added more STLs for Olympus PEN F adapters. STEP to come soon.
    [Olympus PEN-F Mount_M42 Body Cap.step, Olympus PEN-F Mount_M42 Body Cap.stl, Olympus PEN-F Mount_M42-PENF Body.step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]
2023-09-29 Added STEP
    Some file reorganization.
    [baseBodyCap_CEF.stp, baseBodyCap_M42.stp, baseBodyCap_M645.stp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]
2023-09-29 Upload printOrientation Files
    [printOrientation_baseDumbBody_CEF_PENF.3mf, printOrientation_baseDumbBody_M42_PENF.3mf, printOrientation_baseDumbBody_NIKF_PENF.3mf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]
2023-10-16 Upload DKL Mount
    [dumbBody_DKL_PENF.stl, dumbBody_DKL_PENF.stp, mountBodyApertureRing_DKL.stl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]
2023-12-12 Updated some STEP files. Added a few screws to assembilies
    [dumbBody_DKL_PENF.stp, dumbBody_DKL_PENF_assembly.stp, mountBodyApertureRing_DKL.stp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]
2023-12-12 added DUMB adapter assemblies.
    [dumbBody_CEF_PENF_assembly.stp, dumbBody_M42_PENF_assembly.stp, dumbBody_M645_PENF_assembly.stp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]
2025-03-04 Add Canon FD
    [baseBodyCap_CEF.stp, dumbBody_CEF_PENF.stp, dumbBody_CEF_PENF_assembly.stp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]
2025-03-04 updated Canon FD step files
    [baseBodyCap_CEF.stl, dumbBody_CEF_PENF.stl, mountBodyBase_CEF.stl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]
2025-03-05 Updated FD
    [baseBodyCap_CEF.stp, dumbBody_CEF_PENF.stp, dumbBody_CEF_PENF_assembly.stp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]
2025-03-05 Update FD
    [baseBodyCap_CEF.stl, dumbBody_CEF_PENF.stl, dumbBody_CFD_PENF_printOrientation.3mf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]
2025-03-07 removed Canon FD need further testing
    [dumbBody_CFD_PENF.stl, dumbBody_CFD_PENF.stp, dumbBody_CFD_PENF_assembly.stp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]
2025-03-07 Released Canon FD to PEN-F adapter
    [dumbBody_CFD_PENF.stl, dumbBody_CFD_PENF.stp, dumbBody_CFD_PENF_assembly.stp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]
2025-08-07 Uploaded Olympus OM to PENF adapter
    [dumbBodyFlange_OM_PENF.stl, dumbBody_OM_PENF.stl, dumbBody_OM_PENF.stp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]
